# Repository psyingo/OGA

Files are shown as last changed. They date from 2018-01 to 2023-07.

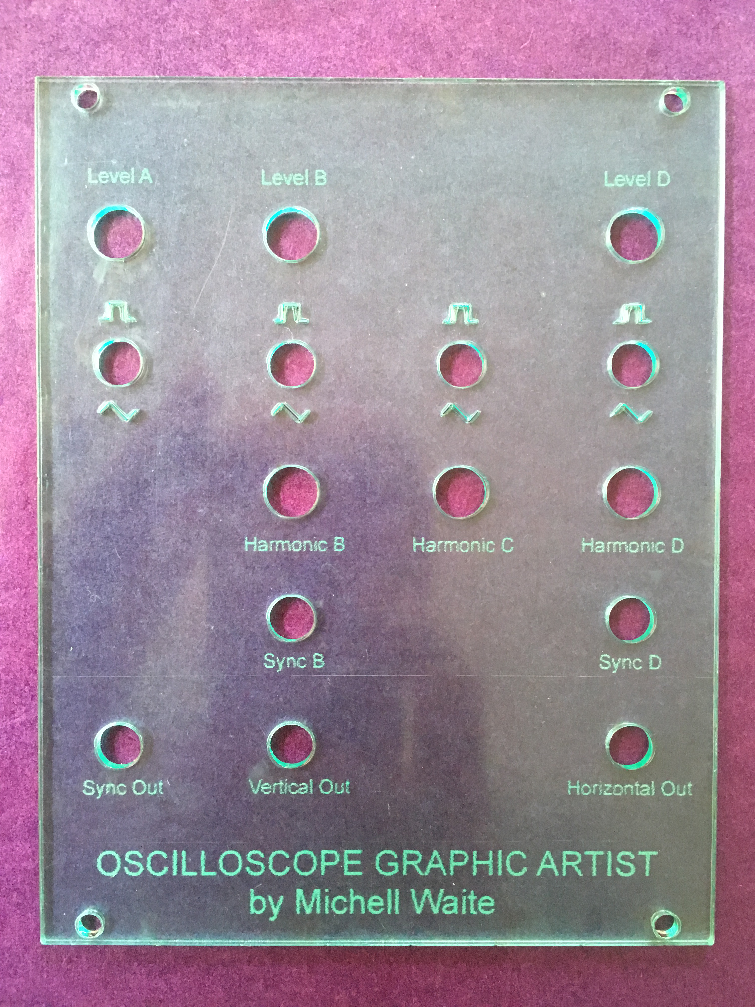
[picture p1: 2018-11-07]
Oscilloscope_Graphic_Artist_Panel/OGA PANEL.JPG

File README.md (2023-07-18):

# OGA

The Oscilloscope graphic artist is a project that was originally designed by Mitchell Waite in the November 1975 issue of Popular Electronics. 
I have made the design in to a PCB project with gerber files and a bill of materials for anyone to make. 
Please do not sell these for profit.
Contact me if you would like me to lead a workshop.
If you host your own workshop please credit me, Phil Baljeu. IG @pbalpbal [http:](https://www.instagram.com/pbalpbal/)https://www.instagram.com/pbalpbal/

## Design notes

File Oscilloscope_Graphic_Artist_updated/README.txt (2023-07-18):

In this file there are two different sets of Gerbers. 
One is for board mount pots that should be mounted East-West (marked EW-pots), and the other for North-South (marked NS-pots). 
I've found some pots mounted differently depending on where the 'pointer' on the knob goes.
Both boards are identical except for this, and traces to accommodate. 
I have marked the timing caps of the oscillators with their respective letters (A,B,C,D) for easy swapping.
The BOM has the same reference designators as the original project, except where a few modifications were added.

please send me an email at phil@occupiedvr.com if anything is incorrect and I will update the project files.

The Oscilloscope graphic artist is a project that was originally designed by Mitchell Waite in the November 1975 issue of Popular Electronics. 
I have made the design in to a PCB project with gerber files and a bill of materials for anyone to make. 
Please do not sell these for profit.
Contact me if you would like me to lead a workshop.
If you host your own workshop please credit me, Phil Baljeu. IG @pbalpbal [http:](https://www.instagram.com/pbalpbal/)https://www.instagram.com/pbalpbal/

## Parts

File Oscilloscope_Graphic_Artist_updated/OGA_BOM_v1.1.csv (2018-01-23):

RefDes | Value | Name | Manufacturer | Quantity
C1, C3 | 47n | CAP100 |  | 2
C2, C4, C10 | 1n | CAP100 |  | 3
C5, C6, C7, C8, C11, C12, C13, C14, C15, C16, C17 | 100n | CAP100 |  | 11
C9 | 10n | CAP100 |  | 1
C18, C19 | 10u 25V | EC80-5 |  | 2
D1, D2 |  | 1N4001 |  | 2
FB1, FB2 | 68R | Ferrite Bead | Fair-Rite | 2
J1 |  | EUROPWR16 |  | 1
J2 | VERT | WQP-PJ398SM | Wenzhou QingPu Electronics Co., Ltd | 1
J3 | HORIZ | WQP-PJ398SM | Wenzhou QingPu Electronics Co., Ltd | 1
J4 | SYNC OUT | WQP-PJ398SM | Wenzhou QingPu Electronics Co., Ltd | 1
Q1, Q2 |  | 2N3819 | ON Semiconductor | 2
R1, R3, R7, R11, R13, R17, R19, R26, R28, R30, R33, R34, R35, R37, R38, R39, R41, R42, R43, R44, R45, R46 | 10K | RES300 |  | 22
R2, R12, R27 | 20K | RES300 |  | 3
R4, R25 | 4.7K | RES300 |  | 2
R5, R6, R9, R10, R14, R18, R21 | 1K | RES300 |  | 7
R8 | 120K | RES300 |  | 1
R15 | 24K | RES300 |  | 1
R16, R23, R31 | 100K | RES300 |  | 3
R20 | 15K | RES300 |  | 1
R22 | 2.7K | RES300 |  | 1
R24 | 47K | RES300 |  | 1
R36, R40 | 470K | RES300 |  | 2
R10-MIXA, R18-MIXB, R32-MIXD | B10K | ALPHA9V | Alpha | 3
R14-FREQB, R21-FREQC, R29-FREQD | 1M | ALPHA9V | Alpha | 3
S1 | WAVEA | 7101K2CBE | C&K | 1
S2 | WAVEB | 7101K2CBE | C&K | 1
S3 | WAVEC | 7101K2CBE | C&K | 1
S4 | WAVED | 7101K2CBE | C&K | 1
S5 | SYNCB | 7101K2CBE | C&K | 1
S6 | SYNCD | 7101K2CBE | C&K | 1
U1, U2, U3 |  | TL074J | Texas Instruments | 3
U4 |  | TL072P | Texas Instruments | 1
 |  |  |  | 89

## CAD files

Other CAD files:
Oscilloscope_Graphic_Artist_Panel/OGA PANEL.dxf

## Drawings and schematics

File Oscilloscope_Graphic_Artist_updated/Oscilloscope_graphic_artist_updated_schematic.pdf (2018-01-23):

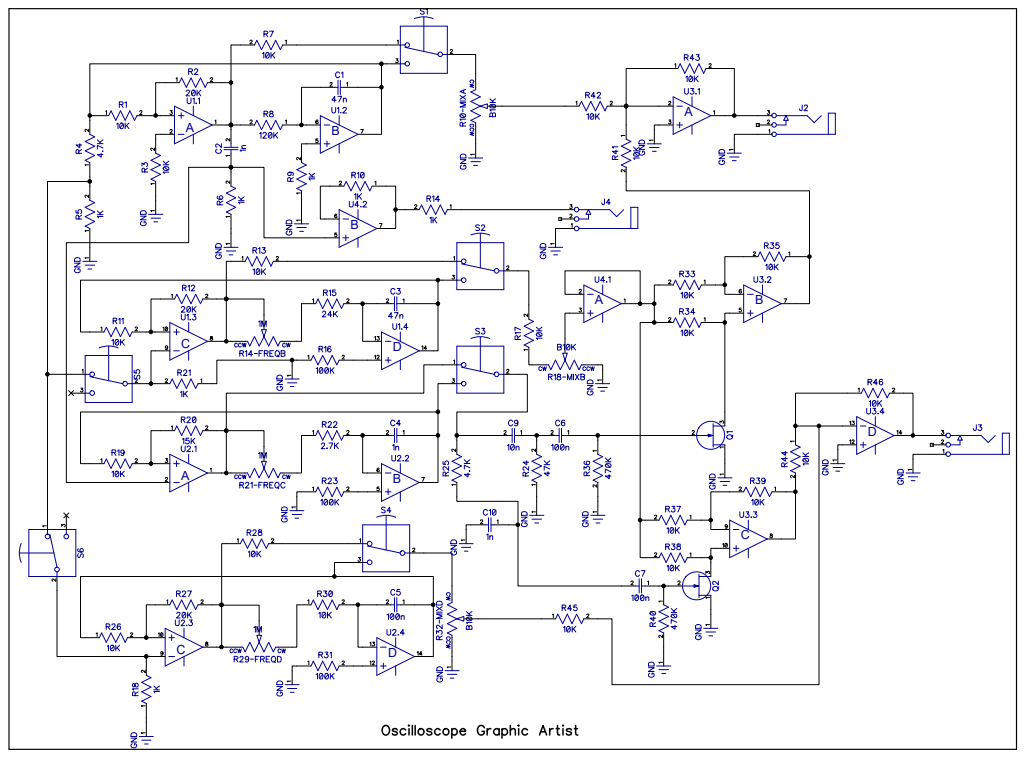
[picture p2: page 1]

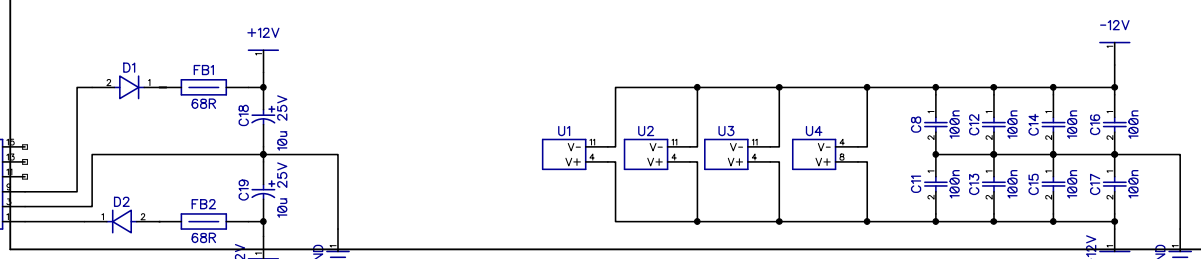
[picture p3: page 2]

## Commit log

2018-01-23 Add files via upload
    Oscilloscope Graphic Artist project, updated from the version on the Video Circuits Facebook group file section.
    [BoardOutline.gbr, Bottom.gbr, BottomAssy.gbr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]
2018-11-07 Oscilloscope Graphic Artist Panel
    [OGA PANEL.dxf]
